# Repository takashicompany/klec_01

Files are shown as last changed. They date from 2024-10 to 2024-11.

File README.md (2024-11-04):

# KLEC-01 "Filled46"

https://x.com/takashicompany/status/1845085013051834711



# 部品リスト

|画像|部品名|個数|備考|
|:--|:--|:--|:--|
||KLEC-01 PCB|1|ガーバデータは[こちら](https://github.com/takashicompany/klec_01/tree/master/gerber)にあります。Kicadのプロジェクトは[こちら](https://github.com/takashicompany/klec_01/tree/master/kicad)です。|
||[Pro Micro](https://shop.yushakobo.jp/products/21)|1|どれを買っていいか分からない場合は[コンスルー付きのセット](https://shop.yushakobo.jp/products/21)の購入を推奨します。|
||[タクトスイッチ](https://shop.yushakobo.jp/products/a0800ts-01-1)|1||
||[コンスルー](https://shop.yushakobo.jp/products/31)|2|PCBとPro Microを接続する端子です。Pro Microに付属するピンヘッダでの取り付けも可能ですが、作業ミスや故障した際の取り替えが容易になりますので、**コンスルーの使用を強く推奨します。ピンヘッダでの取り付けは当キーボードと当ビルドガイドではサポートしません。** コンスルーの必要な高さはPro Microによって異なりますので、販売元にご確認ください。コンスルーについての詳細な説明は[こちら](https://scrapbox.io/self-made-kbds-ja/%E3%82%B3%E3%83%B3%E3%82%B9%E3%83%AB%E3%83%BC)をご一読ください。併せて[取り付け方の説明](https://yushakobo.zendesk.com/hc/ja/articles/360044233974-%E3%82%B3%E3%83%B3%E3%82%B9%E3%83%AB%E3%83%BC-%E3%82%B9%E3%83%97%E3%83%AA%E3%83%B3%E3%82%B0%E3%83%94%E3%83%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)も目を通しておくと作業がスムーズに進められます。|
||[MX互換キースイッチ](https://shop.yushakobo.jp/collections/all-switches)|46||
||[MX互換キーキャップ](https://shop.yushakobo.jp/collections/keycaps)|46|[こちら](https://www.keyboard-layout-editor.com/#/gists/d532e57cda0be36ffc0e33e7f8f69d8d)から各キーのサイズを確認できます。|
||[スタビライザー](https://shop.yushakobo.jp/products/a0500st)|2|
||[ウレタンクッション](https://shop.yushakobo.jp/products/a0800ur-01-6)|6|数はお好みで増減させてください。|
||アクリルケース|1|[こちらのデータ](https://github.com/takashicompany/klec_01/blob/master/case/klec_01_a4_yushakobo.ai)を遊舎工房の[レーザー加工サービス](https://shop.yushakobo.jp/products/lasercut?variant=48787700744423)にてカット依頼するなどして製造してください。後日に[キーボードアクリルプレート](https://shop.yushakobo.jp/products/keyboard_acrylic_plate)に追加予定です。|
||[M2スペーサー](https://shop.yushakobo.jp/products/a0800c2?variant=37665435222177)|8|長さはお好みで調整してください。Pro Microなどにもよりますが、7mm~10mmぐらいがオススメです。|
||[M2ネジ 5mm](https://shop.yushakobo.jp/products/a0800n2?variant=37665432993953)|16||

# ファームウェア

QMK Firmwareで用意しています。
ソースコードは[こちら](https://github.com/takashicompany/qmk_firmware/tree/master/keyboards/takashicompany/klec_01)です。

RemapにVIAファームウェアを登録しておりますので、[こちら](https://remap-keys.app/catalog/Tp7FO3o6xTwo2X9V9IJW/firmware)から書き込みが可能です。
キーマップの変更も[Remap](https://remap-keys.app/)から可能です。

# LICENSE

CC BY-NC 4.0

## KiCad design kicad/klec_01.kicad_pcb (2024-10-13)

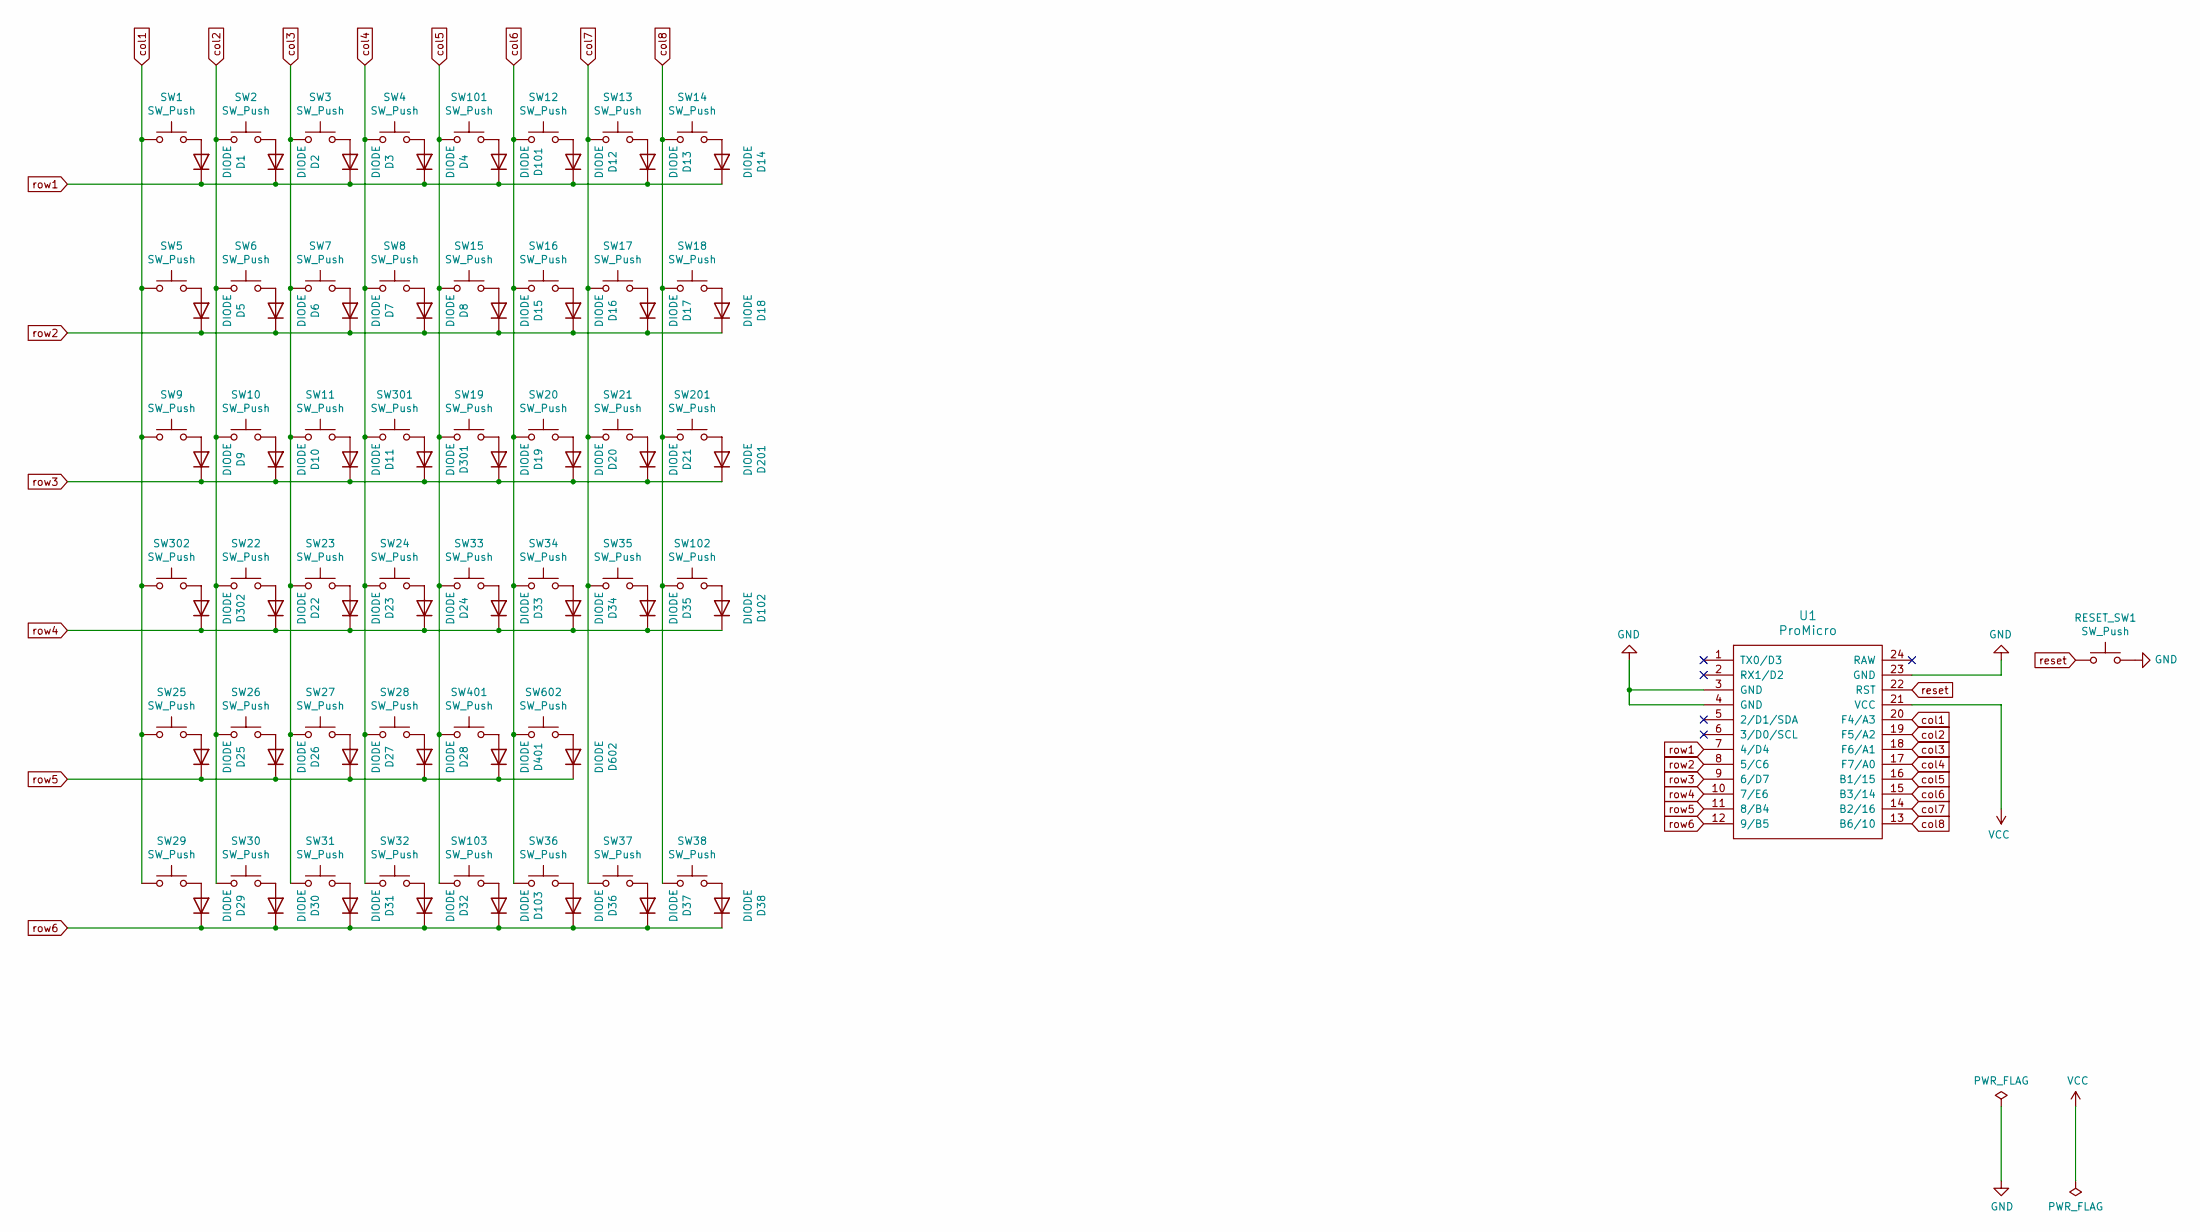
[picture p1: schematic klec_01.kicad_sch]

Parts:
D1, D2, D3, D4, D5, D6, D7, D8, D9, D10, D11, D12, D13, D14, D15, D16, D17, D18, D19, D20, D21, D22, D23, D24, D25, D26, D27, D28, D29, D30, D31, D32, D33, D34, D35, D36, D37, D38, D101, D102, D103, D201, D301, D302, D401, D602: DIODE; D3_TH_SMD_v2
RESET_SW1: SW_Push; ResetSW_1side
SW1, SW2, SW3, SW4, SW5, SW6, SW7, SW8, SW9, SW10, SW11, SW12, SW13, SW14, SW15, SW16, SW17, SW18, SW19, SW20, SW21, SW22, SW23, SW24, SW25, SW26, SW27, SW28, SW29, SW30, SW31, SW32, SW33, SW34, SW35, SW36, SW37, SW38: SW_Push; CherryMX_TH-Hotswap
SW101, SW102, SW103: SW_Push; CherryMX_TH-Hotswap_1.25u
SW201: SW_Push; CherryMX_TH-Hotswap_1.50u
SW301, SW302: SW_Push; CherryMX_TH-Hotswap_1.75u
SW401: SW_Push; CherryMX_TH-Hotswap_2.00u
SW602: SW_Push; CherryMX_TH-Hotswap_2.25u
U1: ProMicro; ProMicro_v3.5_print-inside_back

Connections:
GND: RESET_SW1.2, U1.3 (GND), U1.4 (GND), U1.23 (GND)
unnamed: D1.2 (A), SW1.2
unnamed: D2.2 (A), SW2.2
unnamed: D3.2 (A), SW3.2
unnamed: D4.2 (A), SW4.2
unnamed: D5.2 (A), SW5.2
unnamed: D6.2 (A), SW6.2
unnamed: D7.2 (A), SW7.2
unnamed: D8.2 (A), SW8.2
unnamed: D9.2 (A), SW9.2
unnamed: D10.2 (A), SW10.2
unnamed: D11.2 (A), SW11.2
unnamed: D12.2 (A), SW12.2
unnamed: D13.2 (A), SW13.2
unnamed: D14.2 (A), SW14.2
unnamed: D15.2 (A), SW15.2
unnamed: D16.2 (A), SW16.2
unnamed: D17.2 (A), SW17.2
unnamed: D18.2 (A), SW18.2
unnamed: D19.2 (A), SW19.2
unnamed: D20.2 (A), SW20.2
unnamed: D21.2 (A), SW21.2
unnamed: D22.2 (A), SW22.2
unnamed: D23.2 (A), SW23.2
unnamed: D24.2 (A), SW24.2
unnamed: D25.2 (A), SW25.2
unnamed: D26.2 (A), SW26.2
unnamed: D27.2 (A), SW27.2
unnamed: D28.2 (A), SW28.2
unnamed: D29.2 (A), SW29.2
unnamed: D30.2 (A), SW30.2
unnamed: D31.2 (A), SW31.2
unnamed: D32.2 (A), SW32.2
unnamed: D33.2 (A), SW33.2
unnamed: D34.2 (A), SW34.2
unnamed: D35.2 (A), SW35.2
unnamed: D36.2 (A), SW36.2
unnamed: D37.2 (A), SW37.2
unnamed: D38.2 (A), SW38.2
unnamed: D101.2 (A), SW101.2
unnamed: D102.2 (A), SW102.2
unnamed: D103.2 (A), SW103.2
unnamed: D201.2 (A), SW201.2
unnamed: D301.2 (A), SW301.2
unnamed: D302.2 (A), SW302.2
unnamed: D401.2 (A), SW401.2
unnamed: D602.2 (A), SW602.2
VCC: U1.21 (VCC)
col1: SW1.1, SW5.1, SW9.1, SW25.1, SW29.1, SW302.1, U1.20 (F4/A3)
col2: SW2.1, SW6.1, SW10.1, SW22.1, SW26.1, SW30.1, U1.19 (F5/A2)
col3: SW3.1, SW7.1, SW11.1, SW23.1, SW27.1, SW31.1, U1.18 (F6/A1)
col4: SW4.1, SW8.1, SW24.1, SW28.1, SW32.1, SW301.1, U1.17 (F7/A0)
col5: SW15.1, SW19.1, SW33.1, SW101.1, SW103.1, SW401.1, U1.16 (B1/15)
col6: SW12.1, SW16.1, SW20.1, SW34.1, SW36.1, SW602.1, U1.15 (B3/14)
col7: SW13.1, SW17.1, SW21.1, SW35.1, SW37.1, U1.14 (B2/16)
col8: SW14.1, SW18.1, SW38.1, SW102.1, SW201.1, U1.13 (B6/10)
reset: RESET_SW1.1, U1.22 (RST)
row1: D1.1 (K), D2.1 (K), D3.1 (K), D4.1 (K), D12.1 (K), D13.1 (K), D14.1 (K), D101.1 (K), U1.7 (4/D4)
row2: D5.1 (K), D6.1 (K), D7.1 (K), D8.1 (K), D15.1 (K), D16.1 (K), D17.1 (K), D18.1 (K), U1.8 (5/C6)
row3: D9.1 (K), D10.1 (K), D11.1 (K), D19.1 (K), D20.1 (K), D21.1 (K), D201.1 (K), D301.1 (K), U1.9 (6/D7)
row4: D22.1 (K), D23.1 (K), D24.1 (K), D33.1 (K), D34.1 (K), D35.1 (K), D102.1 (K), D302.1 (K), U1.10 (7/E6)
row5: D25.1 (K), D26.1 (K), D27.1 (K), D28.1 (K), D401.1 (K), D602.1 (K), U1.11 (8/B4)
row6: D29.1 (K), D30.1 (K), D31.1 (K), D32.1 (K), D36.1 (K), D37.1 (K), D38.1 (K), D103.1 (K), U1.12 (9/B5)

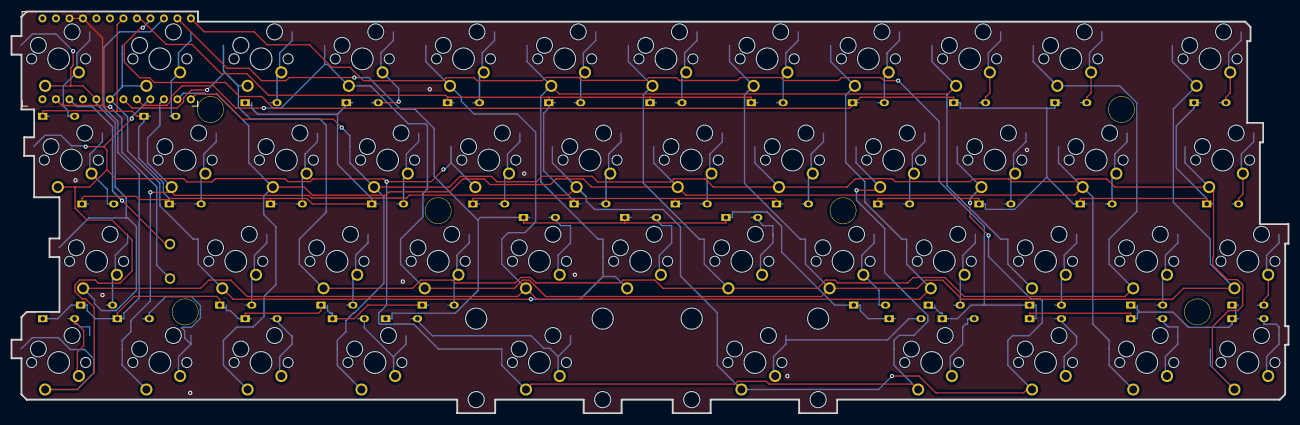
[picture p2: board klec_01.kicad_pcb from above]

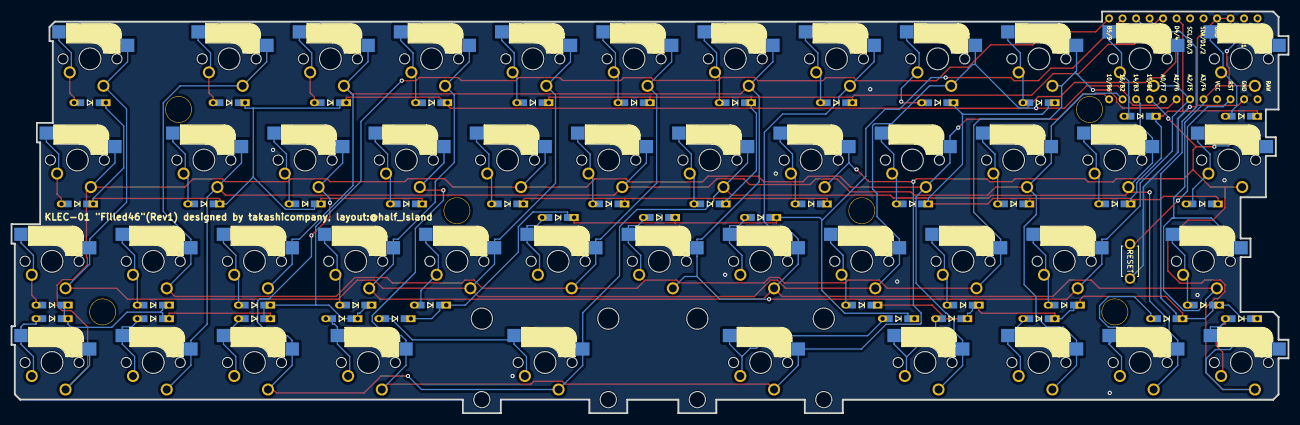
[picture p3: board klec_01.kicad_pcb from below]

Board: 2 copper layers, 240.3 x 75.6 mm, 102 parts (47 on the bottom side), 62 nets.

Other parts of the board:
Hole01, Hole02, Hole03, Hole04, Hole05, Hole06: Val**; HOLE
Stab01, Stab02: Stabilizer_MX_2u

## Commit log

2024-10-13 gerbar and kicad
    [klec_01.kicad_pcb, klec_01.kicad_sch]
2024-11-04 ケースデータ
